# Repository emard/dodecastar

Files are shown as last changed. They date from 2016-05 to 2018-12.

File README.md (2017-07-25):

# Dodecastar

Star-shaped 3D printable object "useful" as a lamp shade
for a string of WS2812B LEDs for Xmas decoration lights.

Dodecastar is a dodecahedron based shape with
12 five-pointed stars, inspired by vintage Xmas
lights from 1960's, made of clear transparent plastic. 
Shape is modified into 2 halves for mounting on LED string.

Written in openscad. To visualize light reflection in
transparent material, it could be exported to "OFF" 
format and imported into Blender.
Example [pictures](/pic/)

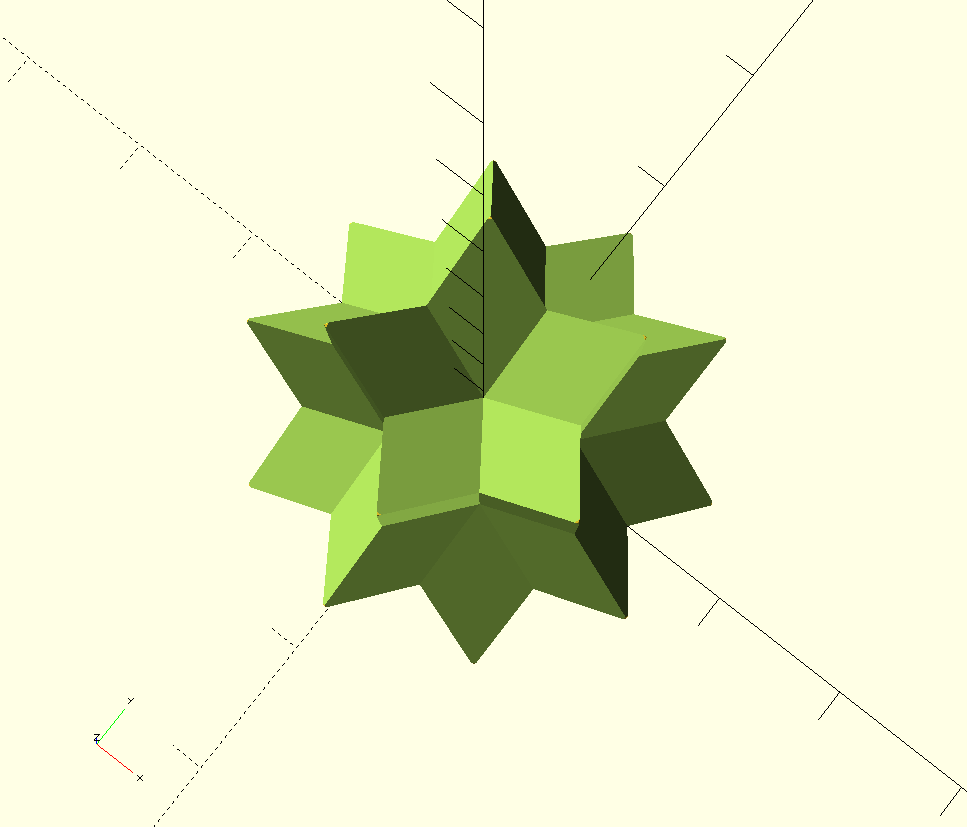
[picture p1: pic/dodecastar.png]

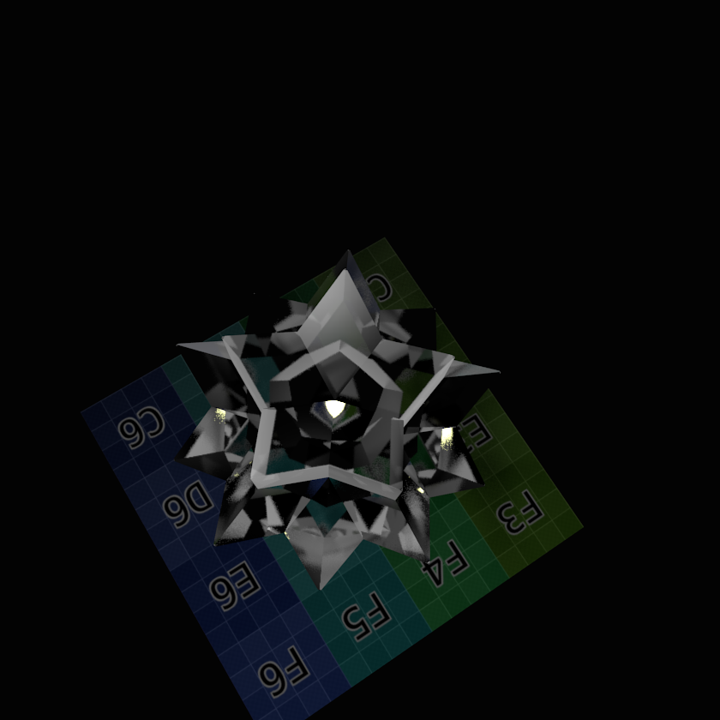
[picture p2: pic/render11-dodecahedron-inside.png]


# Xmas Lights Assembly

The dodecastars are intended to be mounted on a string of
[50Pcs.WS2812B Pre-wired LEDs](http://www.ebay.com/itm/50Pcs-WS2812B-Pre-wired-LED-Pixel-Module-String-Light-Full-Color-5050-RGB-5V-TZ-/201965803082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).

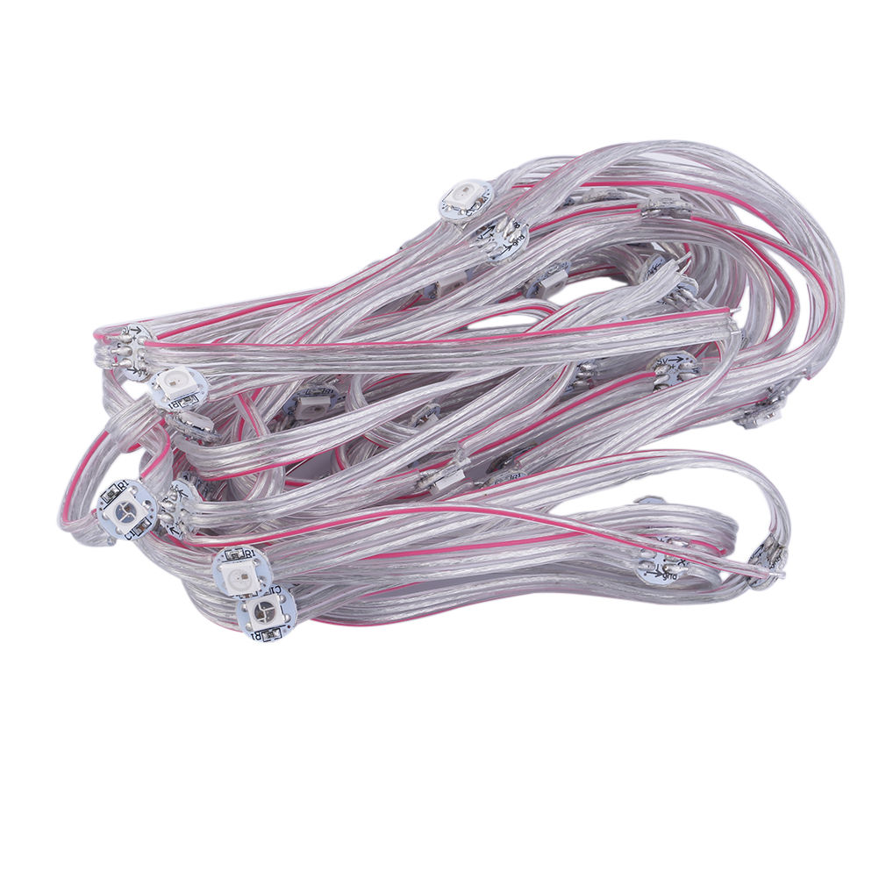
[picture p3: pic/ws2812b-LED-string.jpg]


Each star consists of 2 identical halves, so let's print 100 of them
with transparent colorless filament (I recommend PET-G), infill 0%.
Printing each half takes about 7 minutes. It will appear
as icy-white. It would be ideal if it were really
transparent, but filament extrusion can't make it.

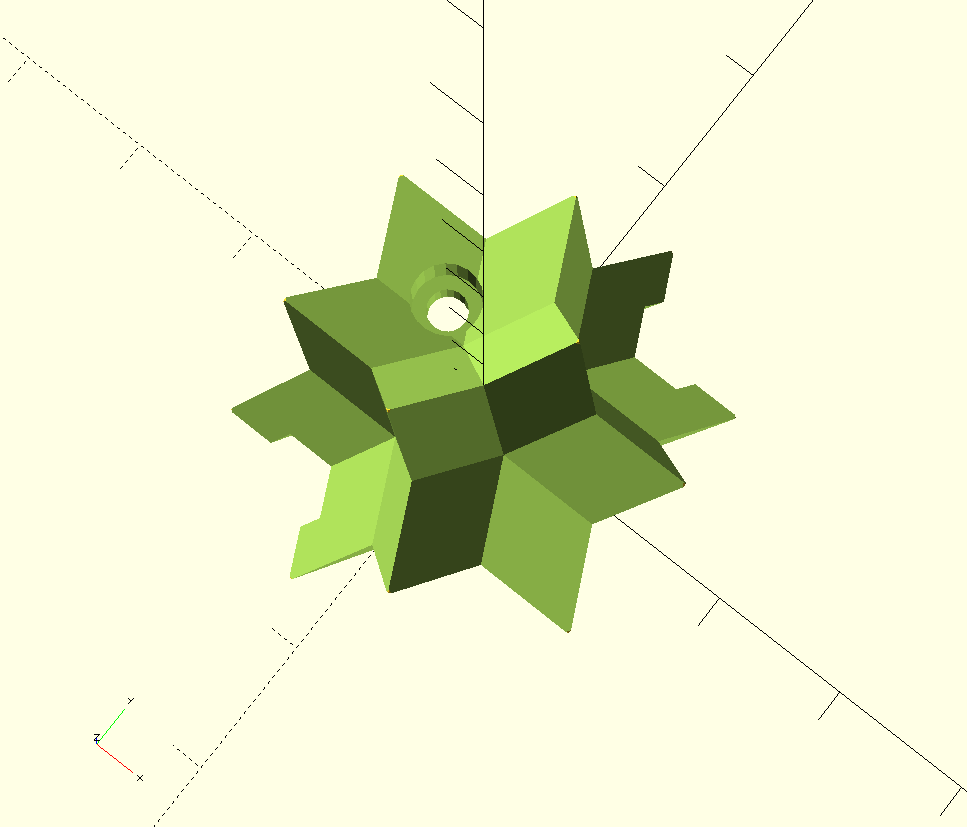
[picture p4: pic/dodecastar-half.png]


Tighten 2 halves of dodecastar gently with 2 small inox screws for 
plastic with round philips head, thread dia: 2.2 mm, thread length: 6 mm.

Carefully handle new LED strip. Soldered connections cannot 
stand any mechanical force. Only mounted dodecastars provide
mechanical strength to whole LED strip.

Solder the USB A male connector on Din side of WS2812B module.
I strongly recommend pinout compatible with normal USB,
so that it can be accidentaly plugged into PC without
any damage, but it will not light up yet because WS2812B 
needs different signal protocol.

    WS2812B    USB-A
    -------    -----
    GND        GND
    Din        D+
               D-
    +5V        +5V

# Hardware

Various [Arduino](http://arduino.cc) compatible hardware 
should work, even ATTINY85.
I use ESP8266 NodeMCU 0.9 with GPIO14 connected to LED Din
(GPIO14 is arduino Pin 2, on NodeMCU is labeled "D5").
Connect GND and 5V from the board to LED strip.
No resistors or capacitors needed for NodeMCU.

# Software

Install [Arduino](http://arduino.cc) and
core support if required for your board.
NodeMCU boards require 
[ESP8266 core for Arduino ](https://github.com/esp8266/Arduino).

Download
[Adafruit NeoPixel library](https://github.com/adafruit/Adafruit_NeoPixel),
copy it to ~/Arduino/libraries/Adafruit_NeoPixel
and restart arduino.

Open Examples->Adafruit NeoPixel->Strandtest.
Edit source to set right PIN connected to "Din"
(pin 14 in my case) and number of LEDs on the strip
(I have 50).

    #define PIN 14 // Arduino pin 14 = NodeMCU pin D5
    Adafruit_NeoPixel strip = Adafruit_NeoPixel(50, PIN, NEO_GRB + NEO_KHZ800);

Compile and upload, whole LED string will light up and
constantly change beautiful colors!

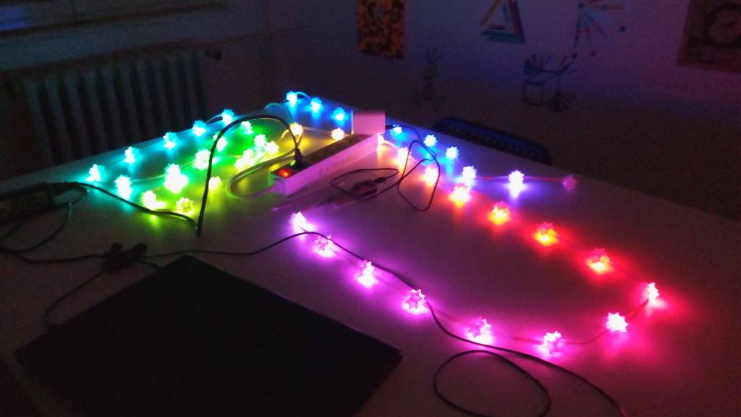
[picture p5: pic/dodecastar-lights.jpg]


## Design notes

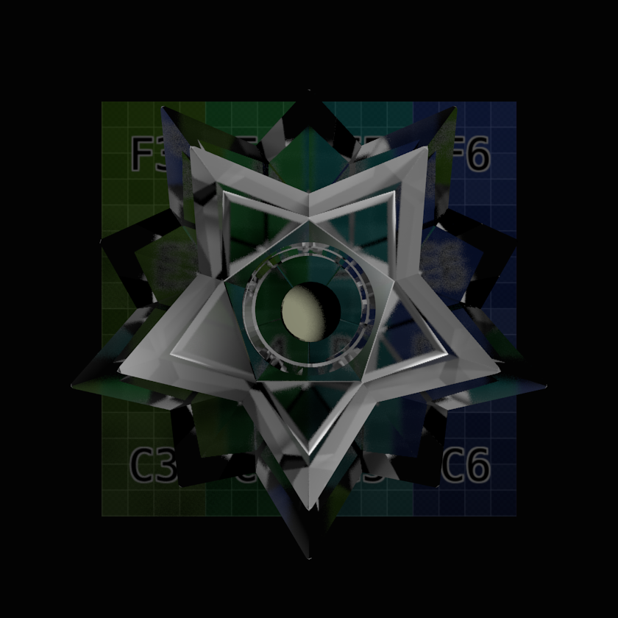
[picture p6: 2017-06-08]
pic/render01-star-inside.png

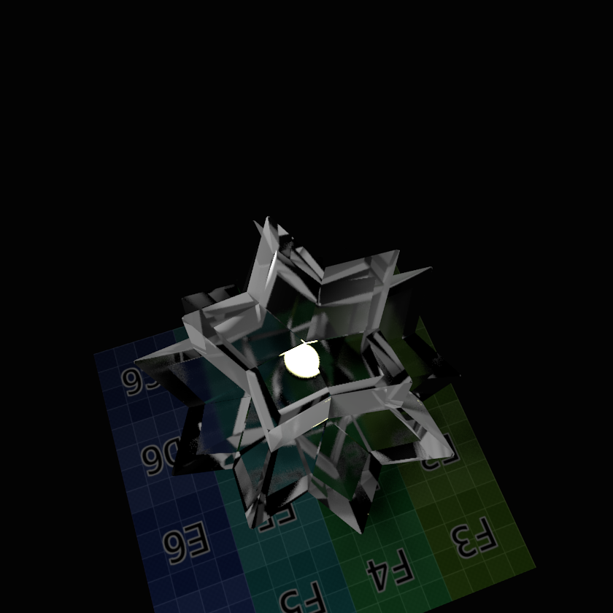
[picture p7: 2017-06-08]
pic/render02-star-inside.png

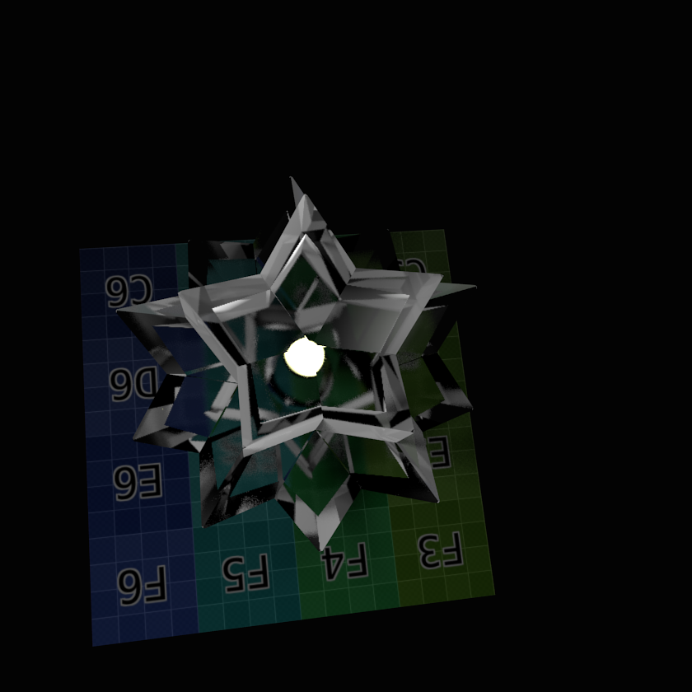
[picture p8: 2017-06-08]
pic/render03-star-inside.png

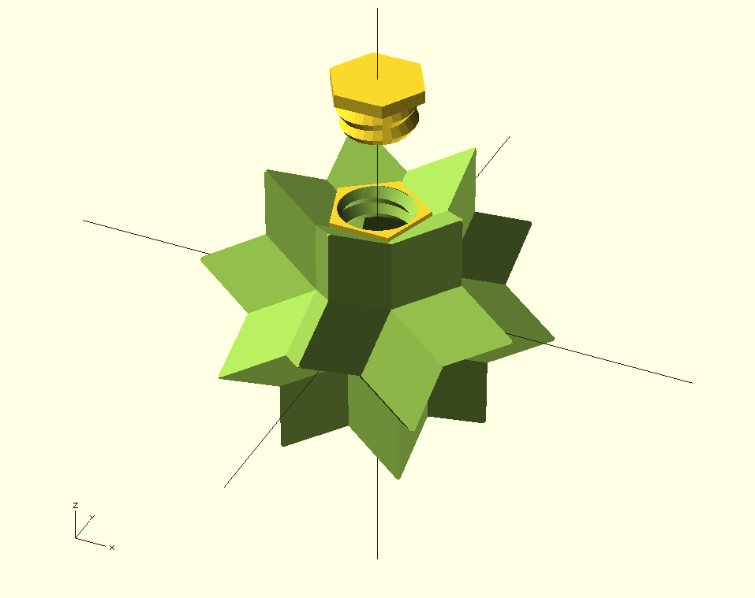
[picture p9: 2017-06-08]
pic/dodecastar12.png

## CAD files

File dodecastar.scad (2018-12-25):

include <polyScrewThread.scad>

/*
todo:
[ ] no thread
[ ] cable strength release
[ ] lamp socket
*/

//create a dodecahedron by intersecting 6 boxes

module pentagonal_cut_up(d, u = 0)
{
  translate([0,0,0.500001-d/2])
    rotate([0,0,90+72/2])
      cylinder(h = d, r1 = 0, r2 = sqrt(2) / 3 - u, $fa = 360/5, $fs = 0.1, center=true);
}

module pentagonal_cut_down(d, u = 0)
{
  translate([0,0,-0.500001+d/2])
    rotate([0,0,90])
      cylinder(h = d, r2 = 0, r1 = sqrt(2) / 3 - u, $fa = 360/5, $fs = 0.1, center = true);
}

/* two pentagonal pyramids, facing peak-to-peak */
/* d - cut depth 
** u - leave uncut edge
*/
module pentagonal_cutter(d, u = 0)
{
  pentagonal_cut_up(d, u);
  pentagonal_cut_down(d, u);
}

/* 
   h = height (mm) (original prism reflector is 43 mm high)

   d = cut depth (unit 0-no cut 1-cut all)
   u = uncut edge roudoff (0-sharp 0.005-slightly rounded)
   l = 0-cut all edges 1-leave top edge uncut

   spiky star with spikes roundoff: d=0.233, u = 0.005
   spiky star with sharp spikes: d=0.233, u = 0

   original:  dodecastar(43, 0.2, u = 0.005);
   improved:  dodecastar(43, 0.233, u = 0.005);
*/
module dodecastar(height = 1, d = 0.233, u = 0.005, l = 0)
{
  scale([height,height,height]) //scale by height parameter
  {
    difference()
    {
      intersection(){
        // make a cube
        cube([2,2,1], center = true); 
        intersection_for(i=[0:4]) //loop i from 0 to 4, and intersect results
        { 
          //make a cube, rotate it 116.565 degrees (dihedral angle)  around the X axis,
          // dihedral angle:
          // golden_ratio = (1 + sqrt(5)) / 2
          // dihedral_angle = 2 * atan(golden_ratio)
          // dihedral_angle = 2 * atan((1 + sqrt(5)) / 2)
          //then 72*i around the Z axis
          rotate([0,0,72*i])
            rotate([2 * atan((1 + sqrt(5)) / 2),0,0])
              cube([2,2,1], center = true); 
        }
      }

      union()
      {
        rotate([0,0,72/2])
          if(l < 0.5)
            pentagonal_cutter(d, u);
          else
            pentagonal_cut_down(d, u);
        for(i = [0:4])
        {
          rotate([0,0,72*i])
            rotate([2 * atan((1 + sqrt(5)) / 2),0,0])
              pentagonal_cutter(d, u);
        }
      }
    }
  }
}

//create a dodecahedron by intersecting 6 boxes
module dodecahedron(height) 
{
        scale([height,height,height]) //scale by height parameter
        {
                intersection(){
                        //make a cube
                        cube([2,2,1], center = true); 
                        intersection_for(i=[0:4]) //loop i from 0 to 4, and intersect results
                        { 
                                //make a cube, rotate it dihedral angle 116.565 degrees around the X axis,
                                // dihedral angle:
                                // golden_ratio = (1 + sqrt(5)) / 2
                                // dihedral_angle = 2 * atan(golden_ratio)
                                // dihedral_angle = 2 * atan((1 + sqrt(5)) / 2)
                                //then 72*i around the Z axis
                                rotate([0,0,72*i])
                                        rotate([2 * atan((1 + sqrt(5)) / 2),0,0])
                                        cube([2,2,1], center = true); 
                        }
                }
        }
}

/* make a lamp hole in the reflector 
** height in mm
** ih: interior dodecastar lamp hole factor (0.7) relative to height
** id: interior dodecastar cut depth (0.15)
** extup: screw hole reinforcement height factor (0.25) relative to height
** interface 0-none, 1-screw hole, 2-ledstrip pass-thru, 3-ledstrip half with 2 screws
interior dodecastar : ih = 0.7, id = 0.15, extup = 0.25
interior simple dodecahedron : ih = 0.5, id = 0, extup = 0.25
*/
module reflector(height = 43, ih = 0.5, id = 0.0, extup = 0.22,
// for interface=3
screw_pos=7,
screw=2.2, screw_thread_d=2.2*0.8, screw_hole_d=2.2*1.3, screw_head_d=2.2*2.2,
screw_head_h=2.2*0.6, screw_length=9.5,
nut_height=1.0, nut_d=2.2*2.1,
cable_w=6, cable_h=1.8,
interface=3)
{
  // additional stuff for interface=3
  star_angle=atan((1 + sqrt(5)) / 2);
  screw_height=screw_length/2-screw_head_h; // height without the head
  rotate([0,interface==3 ? 270 : 0,0])
  union()
  {
    difference()
    {
      union() // material volume
      {
        dodecastar(height);
        /* lamp screw hole, reinforced with extruded pentagon
        ** 0.233 is the cut depth of outer dodecastar
        ** 0.1 is the internal dodecastar-hole cut depth */
        if(interface == 1)
          translate([0,0,height*ih/2 * (1-2*id)])
            rotate([0,0,90])
              cylinder(h = height*(extup+1-0.233*2-ih*(1-2*id))/2, r = 8, $fa = 360/5, $fs = 0.1);
      }
      union() // void volume
      {
        /* cut out dodecastar interior for the lamp */
        // dodecahedron(height*ih);
        dodecastar(height*ih, d = id, u = 0, l = 0);
        /* cut out the screw thread, translate and length same as reinforcement */
/*           8,  // Height 
 *           3,  // Step height (the half will be used to countersink the ends)
 *          55,  // Degrees (same as used for the screw_thread example)
 *          15,  // Outer diameter of the thread to match
 *         0.5)  // Resolution, you may want to set this to small values cca 0.5
 *                  (quite high res) to minimize overhang issues 
 */
        if(interface==1)
          translate([0,0,height*ih/2 * (1-2*id)])
            thread_cut(height*(extup+1-0.233*2-ih*(1-2*id))/2,3,55,12.4,0.5);
        if(interface==2)
          rotate([0,0,30])
          {
            translate([0,-2,0])
              cube([9,3,height], center=true);
            cube([13,1,height], center=true);
          }
        if(interface==3)
        {
          // cube to cut off half-star
          translate([-height,0,0])
            cube([2*height,2*height,2*height], center=true);
          // box to cut off cable holder slit
          rotate([star_angle,0,0])
            cube([cable_h,cable_w,height*1.1],center=true);
          // cylinder to drill screw thru-hole
          // just drill screw head hole thru above
          rotate([0,90,0])
            rotate([0,0,star_angle])
              translate([0,screw_pos,screw_height])
                cylinder(d=screw_head_d-0.001,h=height+0.002,$fn=20,center=false);
          // screw leader hole thru all
          rotate([0,90,0])
            rotate([0,0,star_angle])
              translate([0,screw_pos,-0.001])
                cylinder(d=screw_hole_d,h=height+0.002,$fn=20,center=false);
          // screw hole for the thread
          rotate([0,90,0])
            rotate([0,0,star_angle])
              translate([0,-screw_pos,-0.001])
                cylinder(d=screw_thread_d,h=height*0.22+0.002,$fn=20,center=false);
          // screw leader hole for thread clearance
          rotate([0,90,0])
            rotate([0,0,star_angle])
              translate([0,-screw_pos,-0.001])
                cylinder(d=screw_hole_d,h=nut_height+0.002,$fn=20,center=false);
        }
      }
    }
    if(interface == 3) // post-added volume
    {
      // plastic nut for screw thread
      rotate([0,90,0])
        rotate([0,0,star_angle])
        union()
        {
           translate([0,-screw_pos,height/10+nut_height/2])
             difference()
             {
               cylinder(d=nut_d,h=height/5-nut_height,$fn=20,center=true);
               // hole in the nut for screw thread
               cylinder(d=screw_thread_d,h=height,$fn=20,center=true);
             }
           translate([0,screw_pos,0])
             difference()
             {
               union()
               {
               // the material (the nut)
               // 1.5 mm add to diameter for screw holder thickness
               translate([0,0,nut_height])
                 cylinder(d1=nut_d,d2=screw_head_d+1.5,h=screw_height-nut_height,$fn=20,center=false);
               translate([0,0,screw_height])
                 cylinder(d=screw_head_d+1.5,h=height*0.22-screw_height,$fn=20,center=false);
               }
               // hole in the screw leader
               union()
               {
                 // thru-hole, more than long enough
                 cylinder(d=screw_hole_d, h=height, $fn=20, center=true);
                 // conical screw head
                 translate([0,0,screw_height])
                   cylinder(d1=screw_hole_d,d2=screw_head_d,h=screw_head_h, $fn=20, center=false);
                 translate([0,0,screw_height+screw_head_h])
                   cylinder(d=screw_head_d,h=height,$fn=20,center=false);
               }
             }
        }
    }
  }
}

/* for 3d printing */
/* minimal size (cca 0.5x normal size) that fits ledstrip */
if(1)
    reflector(height=27, screw_head_h=0.001, screw_length=5, cable_h=2.2, interface=3);
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

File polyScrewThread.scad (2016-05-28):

/*
 *    polyScrewThread.scad    by aubenc @ Thingiverse
 *
 * This script contains the library modules that can be used to generate
 * threaded rods, screws and nuts.
 *
 * http://www.thingiverse.com/thing:8796
 *
 * CC Public Domain
 */

module screw_thread(od,st,lf0,lt,rs,cs)
{
    or=od/2;
    ir=or-st/2*cos(lf0)/sin(lf0);
    pf=2*PI*or;
    sn=floor(pf/rs);
    lfxy=360/sn;
    ttn=round(lt/st)+1;
    zt=st/sn;

    intersection()
    {
        if (cs >= -1)
        {
           # thread_shape(cs,lt,or,ir,sn,st);
        }

        full_thread(ttn,st,sn,zt,lfxy,or,ir);
    }
}

module hex_nut(df,hg,sth,clf,cod,crs)
{

    difference()
    {
        hex_head(hg,df);

        hex_countersink_ends(sth/2,cod,clf,crs,hg);

        screw_thread(cod,sth,clf,hg,crs,-2);
    }
}

module thread_cut(hg,sth,clf,cod,crs)
{
    union()
    {
        hex_countersink_ends(sth/2,cod,clf,crs,hg);
        screw_thread(cod,sth,clf,hg,crs,-2);
    }
}

module hex_screw(od,st,lf0,lt,rs,cs,df,hg,ntl,ntd)
{
    ntr=od/2-(st/2+0.1)*cos(lf0)/sin(lf0);

    union()
    {
        hex_head(hg,df);

        translate([0,0,hg])
        if ( ntl == 0 )
        {
            cylinder(h=0.01, r=ntr, center=true);
        }
        else
        {
            if ( ntd == -1 )
            {
                cylinder(h=ntl+0.01, r=ntr, $fn=floor(od*PI/rs), center=false);
            }
            else if ( ntd == 0 )
            {
                union()
                {
                    cylinder(h=ntl-st/2,
                             r=od/2, $fn=floor(od*PI/rs), center=false);

                    translate([0,0,ntl-st/2])
                    cylinder(h=st/2,
                             r1=od/2, r2=ntr, 
                             $fn=floor(od*PI/rs), center=false);
                }
            }
            else
            {
                cylinder(h=ntl, r=ntd/2, $fn=ntd*PI/rs, center=false);
            }
        }

        translate([0,0,ntl+hg]) screw_thread(od,st,lf0,lt,rs,cs);
    }
}

module thread_shape(cs,lt,or,ir,sn,st)
{
    if ( cs == 0 )
    {
        cylinder(h=lt, r=or, $fn=sn, center=false);
    }
    else
    {
        union()
        {
            translate([0,0,st/2])
              cylinder(h=lt-st+0.005, r=or, $fn=sn, center=false);

            if ( cs == -1 || cs == 2 )
            {
                cylinder(h=st/2, r1=ir, r2=or, $fn=sn, center=false);
            }
            else
            {
                cylinder(h=st/2, r=or, $fn=sn, center=false);
            }

            translate([0,0,lt-st/2])
            if ( cs == 1 || cs == 2 )
            {
                  cylinder(h=st/2, r1=or, r2=ir, $fn=sn, center=false);
            }
            else
            {
                cylinder(h=st/2, r=or, $fn=sn, center=false);
            }
        }
    }
}

module full_thread(ttn,st,sn,zt,lfxy,or,ir)
{
    for(i=[0:ttn-1])
    {
        for(j=[0:sn-1])
        {
            polyhedron(
                  points=[
                          [0,                  0,                  i*st-st            ],
                          [ir*cos((j+1)*lfxy), ir*sin((j+1)*lfxy), i*st+(j+1)*zt-st   ],
                          [ir*cos(j*lfxy),     ir*sin(j*lfxy),     i*st+j*zt-st       ],
                          [or*cos((j+1)*lfxy), or*sin((j+1)*lfxy), i*st+(j+1)*zt-st/2 ],
                          [or*cos(j*lfxy),     or*sin(j*lfxy),     i*st+j*zt-st/2     ],
                          [0,                  0,                  i*st+st            ],
                          [ir*cos((j+1)*lfxy), ir*sin((j+1)*lfxy), i*st+(j+1)*zt      ],
                          [ir*cos(j*lfxy),     ir*sin(j*lfxy),     i*st+j*zt          ]
                         ],
               faces=[
                          [0,1,2],
                          [5,6,3],[5,3,0],[0,3,1],
                          [3,4,1],[1,4,2],
                          [3,6,4],[4,6,7],
                          [0,2,4],[0,4,5],[5,4,7],
                          [5,7,6]
                         ],
               convexity=5);
        }
    }
}

module hex_head(hg,df)
{
    cylinder(h=hg, r=df/2/sin(60), $fn=6, center=false);
}

module hex_countersink_ends(chg,cod,clf,crs,hg)
{
    translate([0,0,-0.1])
    cylinder(h=chg+0.01, 
             r1=cod/2, 
             r2=cod/2-(chg+0.1)*cos(clf)/sin(clf),
             $fn=floor(cod*PI/crs), center=false);

    translate([0,0,hg-chg+0.1])
    cylinder(h=chg+0.01, 
             r1=cod/2-(chg+0.1)*cos(clf)/sin(clf),
             r2=cod/2, 
             $fn=floor(cod*PI/crs), center=false);
}

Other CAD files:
upbox.scad
dodecastar.blend

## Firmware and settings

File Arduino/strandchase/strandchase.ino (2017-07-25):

#include <Adafruit_NeoPixel.h>
#ifdef __AVR__
  #include <avr/power.h>
#endif

#define PIN 14 // Arduino pin 14 = NodeMCU pin D5
#define NUM_LEDS 50
// web interface is stable up to 5 LEDs
// for more, web interface will stop working after few clicks
// workaround: in Adafruit_NeoPixel.cpp around line 149
// comment out "noInterrupts()" call
// /*  noInterrupts(); */
// LEDs will flicker with interrupts ON, but web interface should be stable
// Interrupts can be turned ON/OFF with "FLICKER" web button

// Parameter 1 = number of pixels in strip
// Parameter 2 = Arduino pin number (most are valid)
// Parameter 3 = pixel type flags, add together as needed:
//   NEO_KHZ800  800 KHz bitstream (most NeoPixel products w/WS2812 LEDs)
//   NEO_KHZ400  400 KHz (classic 'v1' (not v2) FLORA pixels, WS2811 drivers)
//   NEO_GRB     Pixels are wired for GRB bitstream (most NeoPixel products)
//   NEO_RGB     Pixels are wired for RGB bitstream (v1 FLORA pixels, not v2)
//   NEO_RGBW    Pixels are wired for RGBW bitstream (NeoPixel RGBW products)
Adafruit_NeoPixel strip = Adafruit_NeoPixel(NUM_LEDS, PIN, NEO_GRB + NEO_KHZ800);

// IMPORTANT: To reduce NeoPixel burnout risk, add 1000 uF capacitor across
// pixel power leads, add 300 - 500 Ohm resistor on first pixel's data input
// and minimize distance between Arduino and first pixel.  Avoid connecting
// on a live circuit...if you must, connect GND first.

// remote updates over the air
// (>1M flash required)
#define USE_OTA 0

#define SERIAL_VERBOSE 0


// includes
#include <ESP8266WiFi.h>
#include <ESP8266mDNS.h>
#include <WiFiUdp.h>
#include <FS.h>
#if USE_OTA
#include <ArduinoOTA.h>
#endif
#include <ESP8266WebServer.h>

/**
 * mDNS and OTA Constants
 */
#define HOSTNAME "dodecastar-" ///< Hostename. The setup function adds the Chip ID at the end.
/// @}

#define COUNTDOWN_CYCLES 10
int countdown = COUNTDOWN_CYCLES; // improve web stability after clicking, do some loop() cycles without ledstrip update
int allow_interrupts = 1; // no interrupts: web stability only with no interrupts, interrupts: noflicker
int program_control = 1; // blink leds using program control
int program_speed = 5; // how fast
int program_density = 2; // how dense does the color changes between pixels
int program_brightness = 50; // intensity of the LEDs
uint32_t selected_color = strip.Color(100,100,100); // medium white
uint8_t use_color = 0;

/**
 * Default WiFi connection information.
 */
const char* ap_default_ssid = "ra"; ///< Default SSID.
const char* ap_default_psk = "GigabyteBrix"; ///< Default PSK.
//const char* ap_default_psk = ""; ///< Default PSK.
const char* config_name = "./dodecastar.conf";
// set to 0 to start with default ssid/psk
#define LOAD_CONFIG 1
int ap_mode=0;

String current_ssid = ap_default_ssid;
String current_psk = ap_default_psk;

String message = "";
ESP8266WebServer server(80);
String webString="";     // String to display (runtime modified)

// too many controls will make web interface unstable
// enable checkbox for leds
#define WEB_TAB_CHECKBOX 0
// enable on-off buttons for leds
#define WEB_TAB_BUTTON 1
// enable individual color selectors
#define WEB_TAB_COLOR 0


int ssr_cols = 5, ssr_rows = NUM_LEDS/5; // ssr display shown as table cols x rows

uint32_t led_color[NUM_LEDS];
uint8_t led_on[NUM_LEDS]; // click for on/off

int nextline(String content, int pos1)
{
  // Check if there is a second line available.
  int16_t pos = content.substring(pos1).indexOf("\r\n");
  uint16_t le = 2;
  // check for linux and mac line ending.
  if (pos == -1)
  {
    le = 1;
    pos = content.substring(pos1).indexOf("\n");
    if (pos == -1)
      pos = content.substring(pos1).indexOf("\r");
  }
  if(pos == -1)
    return -1;
  return pos1+pos+le; // to start of next line  
}

/**
 * Read WiFi connection information from file system.
 * ssid String pointer for storing SSID.
 * pass String pointer for storing PSK.
 * return True or False.
 * 
 * The config file have to containt the WiFi SSID in the first line
 * and the WiFi PSK in the second line.
 * Line seperator can be \r\n (CR LF) \r or \n.
 */
bool loadConfig(String *ssid, String *pass)
{
  // open file for reading.
  File configFile = SPIFFS.open(config_name, "r");
  if (!configFile)
  {
    Serial.print("Failed to load ");
    Serial.println(config_name);
    return false;
  }

  // Read content from config file.
  String content = configFile.readString();
  configFile.close();
  
  content.trim();

  // Check if there is a second line available.
  int16_t pos = content.indexOf("\r\n");
  uint16_t le = 2;
  // check for linux and mac line ending.
  if (pos == -1)
  {
    le = 1;
    pos = content.indexOf("\n");
    if (pos == -1)
      pos = content.indexOf("\r");
  }

  // If there is no second line: Some information is missing.
  if (pos == -1)
  {
    Serial.println("Infvalid content.");
    Serial.println(content);
    return false;
  }

  // check for the third line
  // Check if there is a second line available.
  int16_t pos2 = content.indexOf("\r\n", pos + le + 1);
  uint16_t le2 = 2;
  // check for linux and mac line ending.
  if (pos2 == -1)
  {
    le2 = 1;
    pos2 = content.indexOf("\n", pos + le + 1);
    if (pos2 == -1)
      pos2 = content.indexOf("\r", pos + le + 1);
  }
  
  // If there is no third line: Some information is missing.
  if (pos2 == -1)
  {
    Serial.println("Invalid content.");
    Serial.println(content);
    return false;
  }

  // Store SSID and PSK into string vars.
  *ssid = content.substring(0, pos);
  *pass = content.substring(pos + le, pos2);

  // get LED state
  pos = pos2 + le2;
  for(int i = 0; i < NUM_LEDS && pos2 >= 0; i++)
  {
    pos2 = nextline(content, pos);
    if(pos >= 0)
    {
      led_color[i] = content.substring(pos,pos2).toInt();
      led_on[i] = led_color[i] ? 1 : 0;
    }
    pos = pos2;
  }
  output_state();

  ssid->trim();
  pass->trim();

#ifdef SERIAL_VERBOSE
  Serial.println("----- connection -----");
  Serial.println("ssid: " + *ssid);
  Serial.println("psk:  " + *pass);
#endif

  return true;
} // loadConfig


/**
 * @brief Save WiFi SSID and PSK to configuration file.
 * @param ssid SSID as string pointer.
 * @param pass PSK as string pointer,
 * @return True or False.
 */
bool saveConfig(String *ssid, String *pass)
{
  // Open config file for writing.
  File configFile = SPIFFS.open(config_name, "w");
  if (!configFile)
  {
    Serial.print("Failed to save ");
    Serial.println(config_name);
    return false;
  }

  // Save SSID and PSK.
  configFile.println(*ssid);
  configFile.println(*pass);

  for(int i = 0; i < NUM_LEDS; i++)
  {
    configFile.println(led_on[i] ? led_color[i] : 0);
    // Serial.println(led_color[i]);
  }
  configFile.close();
  Serial.print("config saved: ");
  Serial.println(config_name);
  return true;
} // saveConfig

// format filesystem (erase everything)
// place default password file
void format_filesystem(void)
{
  String station_ssid = ap_default_ssid;
  String station_psk = ap_default_psk;

  Serial.println("Formatting"); // erase everything
  SPIFFS.format();
  
  Serial.println("Saving factory default");
  saveConfig(&station_ssid, &station_psk);
}

// output led state to hardware pins
void output_state()
{
  for(int i = 0; i < strip.numPixels() && i < NUM_LEDS; i++)
    strip.setPixelColor(i, led_on[i] ? led_color[i] : 0);
}


// greate html table
// that displays ssr state
// in color and has submit buttons
void create_message()
{
  int n = 0;
  message =
"<style type=\"text/css\">"
"input[type=checkbox]"
"{"
 "/* Double-sized Checkboxes */"
 "-ms-transform: scale(2); /* IE */"
 "-moz-transform: scale(2); /* FF */"
 "-webkit-transform: scale(2); /* Safari and Chrome */"
 "-o-transform: scale(2); /* Opera */"
 "padding: 10px;"
"}"
"</style>"
"<head>"
"<meta http-equiv=\"cache-control\" content=\"max-age=0\" />"
"<meta http-equiv=\"cache-control\" content=\"no-cache\" />"
"<meta http-equiv=\"expires\" content=\"0\" />"
"<meta http-equiv=\"expires\" content=\"Tue, 01 Jan 1980 1:00:00 GMT\" />"
"<meta http-equiv=\"pragma\" content=\"no-cache\" />"
"</head>"
            "<a href=\"/\">refresh</a> "
            "<a href=\"setup\">setup</a> "
            "<a href=\"cssButton\">cssButton</a> "
            "<p/>"
            "<form action=\"/update\" method=\"get\" autocomplete=\"off\">";
  char hexcolor[10];
  sprintf(hexcolor, "#%06X", selected_color);
  // color for LED on/off
  message +=     "COLOR "
                 "<input type=\"color\" name=\"selected_color" + String(n) + "\" value=\"" + String(hexcolor) + "\"> </input>"
                 "<input type=\"checkbox\" name=\"use_color\" " + String(use_color ? " checked" : "") + "> </input>"
                 "<p/>";
  // this controls each individual LED on the strip
  message += "<table>";
  for(int y = 0; y < ssr_rows; y++)
  {
    message += "<tr>";
    for(int x = 0; x < ssr_cols; x++)
    {
      sprintf(hexcolor, "#%06X", led_color[n]);
      message += "<td bgcolor=\"" + String(hexcolor) + "\">"
               #if WEB_TAB_CHECKBOX
               + "<input type=\"checkbox\" name=\"check" + String(n) + "\" " + String(led_on[n] ? " checked" : "") + "> </input>"
               #endif
               #if WEB_TAB_COLOR
               + "<input type=\"color\" name=\"color" + String(n) + "\" value=\"" + String(hexcolor) + "\"> </input>"
               #endif
               #if WEB_TAB_BUTTON
               + "<button type=\"submit\" name=\"button"
               + String(n) 
               + "\" value=\"" 
               + String(led_on[n] ? "0" : "1") 
               + "\">" // toggle when clicked 
               + String(led_on[n] ? "ON" : "OFF") // current state
               + "</button>"
               #endif
                 "</td>";
      n++; // increment ssr number
    }
    message += "</tr>";
  }
  message += "</table>";
  // interrupts on/off
  message +=     "FLICKER "
                 " <button type=\"submit\" name=\"interrupt_btn\" value=\"" 
               + String(allow_interrupts ? "0" : "1") 
               + "\">" // toggle when clicked 
               + String(allow_interrupts ? "ON" : "OFF") // current state
               + "</button>"
               + String(allow_interrupts ? "" : " if LED strip stops responding, power OFF/ON")
               + "<p/>";
  // program control on/off
  message +=     "PROGRAM "
                 " <button type=\"submit\" name=\"program_btn\" value=\"" 
               + String(program_control ? "0" : "1") 
               + "\">" // toggle when clicked 
               + String(program_control ? "ON" : "OFF") // current state
               + "</button>"
                 "<p/>";
  // program speed
  message +=     "SPEED "
               " <input type=\"number\" name=\"speed\" value=\"" 
               + String(program_speed) 
               + "\" min=\"1\" max=\"10\">"
                 "<p/>";
  // program density
  message +=     "DENSITY "
               " <input type=\"number\" name=\"density\" value=\"" 
               + String(program_density)
               + "\" min=\"1\" max=\"10\">"
                 "<p/>";
  // program brightness
  message +=     "BRIGHTNESS "
               " <input type=\"number\" name=\"brightness\" value=\"" 
               + String(program_brightness)
               + "\" min=\"0\" max=\"256\">"
                 "<p/>";

  message += "<button type=\"submit\" name=\"apply\" value=\"1\">Apply</button>"
             "<button type=\"submit\" name=\"save\" value=\"1\">Save</button>";
 
  message += "</form>";
}

// when user requests root web page
void handle_root()
{
  create_message();
  server.send(200, "text/html", message);
  countdown = COUNTDOWN_CYCLES;
}

void handle_setup() {
  String new_ssid = "", new_psk = "";
  webString = "<form action=\"/setup\" method=\"get\" autocomplete=\"off\">"
              "Access point: <input type=\"text\" name=\"ssid\"><br>"
              "Password: <input type=\"text\" name=\"psk\"><br>"
              "<button type=\"submit\" name=\"apply\" value=\"1\">Apply</button>"
              "<button type=\"submit\" name=\"discard\" value=\"1\">Discard</button>"
              "</form>";
  for(int i = 0; i < server.args(); i++)
  {
    if(server.argName(i) == "discard")
    {
      loadConfig(&current_ssid, &current_psk);
      create_message();
      webString = message;
    }
    if(server.argName(i) == "apply")
    {
      for(int j = 0; j < server.args(); j++)
      {
        if(server.argName(j) == "ssid")
        {
          new_ssid = server.arg(j);
        }
        if(server.argName(j) == "psk")
        {
          new_psk = server.arg(j);
        }
      }
      if(new_ssid.length() > 0 && new_psk.length() >= 8)
      {
        //Serial.println("Save config");
        current_ssid = new_ssid;
        current_psk = new_psk;
        //saveConfig(&current_ssid, &current_psk);
        //reboot = 1;
        //loadConfig(&current_ssid, &current_psk);
        create_message();
        webString = message 
          + String("Click Save for new login:<p/>")
          + "Access point: " + current_ssid + "<br/>"
          + "Password: " + current_psk + "<p/>"
          + "Settings will be active after next power up.";
      }
    }
  }
  server.send(200, "text/html", webString);            // send to someones browser when asked
  countdown = COUNTDOWN_CYCLES;
}

void handle_update() {
  // first obtain selected color
  char hexcolor[10];
  uint32_t bincolor;
  int color_need = 2; // helps earlier exit
  for(int i = 0; i < server.args() && color_need > 0; i++)
  {
    if(server.argName(i).startsWith("selected_color"))
    {
      server.arg(i).substring(1).toCharArray(hexcolor, 7);
      bincolor = strtol(hexcolor, NULL, 16);
      selected_color = strip.Color((bincolor >> 16) & 255, (bincolor >> 8) & 255, bincolor & 255);
      color_need--;
    }
    if(server.argName(i).startsWith("use_color"))
    {
      use_color = (server.arg(i) == "on") ? 1 : 0;
      color_need--;
    }
  }
  // Apply or Save button
  for(int i = 0; i < server.args(); i++)
  {
    if(server.argName(i) == "apply" || server.argName(i) == "save")
    {
      #if WEB_TAB_CHECKBOX
      // assume all LEDs are off
      for(int j = 0; j < NUM_LEDS; j++)
        led_on[j] = 0;
      #endif
      for(int j = 0; j < server.args(); j++)
      {
        #if WEB_TAB_CHECKBOX
        if(server.argName(j).startsWith("check"))
        {
          int n = server.argName(j).substring(5).toInt();
          if(n >= 0 && n < NUM_LEDS)
            if(server.arg(j) == "on")
              led_on[n] = 1;
        }
        #endif
        #if WEB_TAB_COLOR
        if(server.argName(j).startsWith("color"))
        {
          int n = server.argName(j).substring(5).toInt();
          if(n >= 0 && n < NUM_LEDS)
          {
            server.arg(j).substring(1).toCharArray(hexcolor, 7);
            bincolor = strtol(hexcolor, NULL, 16);
            led_color[n] = strip.Color((bincolor >> 16) & 255, (bincolor >> 8) & 255, bincolor & 255);
          }
        }
        #endif
      }
    }
    if(server.argName(i) == "save")
      saveConfig(&current_ssid, &current_psk);
  }
  // ON/OFF buttons
  for(int i = 0; i < server.args(); i++)
  {
    #if WEB_TAB_BUTTON
    if(server.argName(i).startsWith("button"))
    {
      int n = server.argName(i).substring(6).toInt();
      if(n >= 0 && n < NUM_LEDS)
      {
        uint8_t led_on_off = server.arg(i).toInt() ? 1 : 0;
        if(led_on[n] != led_on_off) // state changed
        {
          led_on[n] = led_on_off;
          if(use_color)
            led_color[n] = selected_color;
        }
      }
    }
    #endif
    if(server.argName(i).startsWith("interrupt_btn"))
      allow_interrupts = server.arg(i).toInt();
    if(server.argName(i).startsWith("program_btn"))
      program_control = server.arg(i).toInt();
    if(server.argName(i).startsWith("speed"))
      program_speed = server.arg(i).toInt();
    if(server.argName(i).startsWith("density"))
      program_density = server.arg(i).toInt();
    if(server.argName(i).startsWith("brightness"))
      program_brightness = server.arg(i).toInt();
  }
  if(program_control == 0)
    output_state();
  create_message();
  webString = message;
  #if 0
  // some debugging print post/get messages
  webString += ( server.method() == HTTP_GET ) ? "GET" : "POST";
  for (int i = 0; i < server.args(); i++ )
  {
    webString += " " + server.argName(i) + ": " + server.arg(i);
  };
  #endif
  server.send(200, "text/html", webString);
  countdown = COUNTDOWN_CYCLES;
}

// fancy css color button example
void handle_cssButton()
{
  const char * cssButton ="<!DOCTYPE html>"
"<html>"
"<head>"
"<style>"
".button {"
"background-color: #990033;"
"border: none;"
"color: white;"
"padding: 7px 15px;"
"text-align: center;"
"cursor: pointer;"
"}"
"</style>"
"</head>"
"<body>"
"<input type=\"button\" class=\"button\" value=\"Input Button\">"
"</body>"
"</html>";

  server.send(200, "text/html", cssButton);
}
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
void loop() {
  static int connect_requested = 1;
  #if USE_OTA
  // Handle OTA server.
  ArduinoOTA.handle();
  #endif
  // Handle web server
  server.handleClient();
  if(countdown > 0)
    countdown--;
  else
  {
    if(program_control > 0)
      program();
    if(allow_interrupts == 0)
      noInterrupts();
    strip.show(); // it will disable interrupts
    interrupts(); // re-enable interrupts
    if(WiFi.status() == WL_CONNECTED)
    {
      digitalWrite(LED_BUILTIN, LOW); // LED ON
      connect_requested = 0; // if we loose connection, we have to reboot
    }
    else
    {
      digitalWrite(LED_BUILTIN, HIGH); // LED OFF
      // we were connected -> reboot to reconnect
      if(connect_requested == 0 && ap_mode == 0)
      {
        proper_reboot_pins();
        // explicitely reset
        // warning - reset won't work after sketch is uploaded.
        // but after power off/on it should work
        ESP.reset();
        // or reset in 6 seconds by hard watchdog
        // some problem in watchdog reset...
        ESP.wdtDisable();
        while(1){} // wait for watchdog to reset
      }
    }

  }
  ESP.wdtFeed();
#if 0
  // Some example procedures showing how to display to the pixels:
  colorWipe(strip.Color(255,   0,   0), 40); // Red
  colorWipe(strip.Color(255, 127,   0), 40); // Orange
  colorWipe(strip.Color(  0, 255,   0), 40); // Green
  colorWipe(strip.Color(  0, 127, 127), 40); // Cyan
  colorWipe(strip.Color(  0,   0, 255), 40); // Blue
  colorWipe(strip.Color(255,   0, 127), 40); // Violett
  colorWipe(strip.Color(  0,   0,   0), 40); // Black
  //colorWipe(strip.Color(0, 0, 0, 255), 40); // White RGBW
  //delay(1000);
  for(int i = 0; i < 3; i++)
    rainbow(20);
  // Send a theater pixel chase in...
  theaterChase(strip.Color(255, 127,   0), 16, 2, 20); // Orange
  theaterChase(strip.Color(255,   0, 127), 16, 2, 20); // Violett
  theaterChase(strip.Color(127, 127, 127), 16, 2, 20); // White
  rainbowCycle(20);
  theaterChaseRainbow(32, 20);
#endif
}

// Fill the dots one after the other with a color
void colorWipe(uint32_t c, uint8_t wait) {
  for(uint16_t i=0; i<strip.numPixels(); i++) {
    strip.setPixelColor(i, c);
    strip.show();
    delay(wait);
  }
}

void rainbow(uint8_t wait) {
  uint16_t i, j;

  for(j=0; j<256; j++) {
    for(i=0; i<strip.numPixels(); i++) {
      strip.setPixelColor(i, Wheel((i+j) & 255));
    }
    strip.show();
    delay(wait);
  }
}

// Slightly different, this makes the rainbow equally distributed throughout
void rainbowCycle(uint8_t wait) {
  uint16_t i, j;

  for(j=0; j<256*5; j++) { // 5 cycles of all colors on wheel
    for(i=0; i< strip.numPixels(); i++) {
      strip.setPixelColor(i, Wheel(((i * 256 / strip.numPixels()) + j) & 255));
    }
    strip.show();
    delay(wait);
  }
}

//Theatre-style crawling lights.
void theaterChase(uint32_t c, uint8_t every, uint8_t n, uint8_t wait) {
  for (int j=0; j<n; j++) {  //do n cycles of chasing
    for (int q=0; q < every; q++) {
      for (uint16_t i=0; i < strip.numPixels(); i=i+every) {
        strip.setPixelColor(i+q, c);    //turn every nth pixel on
      }
      strip.show();

      delay(wait);

      for (uint16_t i=0; i < strip.numPixels(); i=i+every) {
        strip.setPixelColor(i+q, 0);        //turn every nth pixel off
      }
    }
  }
}

//Theatre-style crawling lights with rainbow effect
void theaterChaseRainbow(uint8_t every, uint8_t wait) {
  for (int j=0; j < 256; j+=16) {     // cycle all 256 colors in the wheel
    for (int q=0; q < every; q++) {
      for (uint16_t i=0; i < strip.numPixels(); i=i+every) {
        strip.setPixelColor(i+q, Wheel( (i+j) % 255));    //turn every third pixel on
      }
      strip.show();

      delay(wait);

      for (uint16_t i=0; i < strip.numPixels(); i=i+every) {
        strip.setPixelColor(i+q, 0);        //turn every third pixel off
      }
    }
  }
}

// Input a value 0 to 255 to get a color value.
// The colours are a transition r - g - b - back to r.
uint32_t Wheel(byte WheelPos) {
  WheelPos = 255 - WheelPos;
  if(WheelPos < 85) {
    return strip.Color(255 - WheelPos * 3, 0, WheelPos * 3);
  }
  if(WheelPos < 170) {
    WheelPos -= 85;
    return strip.Color(0, WheelPos * 3, 255 - WheelPos * 3);
  }
  WheelPos -= 170;
  return strip.Color(WheelPos * 3, 255 - WheelPos * 3, 0);
}

uint32_t Wheel_bright(byte WheelPos, byte brightness) {
  uint32_t r,g,b;
  WheelPos = 255 - WheelPos;
  if(WheelPos < 85) {
    r = 255 - WheelPos * 3;
    g = 0;
    b = WheelPos * 3;
  } else
  if(WheelPos < 170) {
    WheelPos -= 85;
    r = 0;
    g = WheelPos * 3;
    b = 255 - WheelPos * 3;
  } else
  {
    WheelPos -= 170;
    r = WheelPos * 3;
    g = 255 - WheelPos * 3;
    b = 0;
  }
  r = r * brightness / 256;
  g = g * brightness / 256;
  b = b * brightness / 256;
  return strip.Color(r, g, b);
}

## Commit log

2016-05-28 add thread library
    [polyScrewThread.scad]
2016-05-28 replacing obsolete triangles with new faces
    [polyScrewThread.scad]
2016-06-04 increasing inner diameter of the reflector thread to 12.4 mm to fit tolaerance of the screw printed as 12.0 mm
    [dodecastar.scad]
2017-05-28 2 half-star with 2 screws
    [dodecastar.scad]
2017-06-01 update half with screw mount
    [dodecastar.scad]
2017-06-01 parametric screw hole
    [dodecastar.scad]
2017-06-02 add parametric screw hole and cable holder space
    [dodecastar.scad]
2017-06-02 icreasing screw hole
    [dodecastar.scad]
2017-06-02 parametrizing and adjusting screw head hole dimensions
    [dodecastar.scad]
2017-06-03 orienting half-star flat on xy plane
    [dodecastar.scad]
2017-06-04 screw parameters as function arguments
    [dodecastar.scad]
2017-06-04 trying to fix when screw length is small and gets deep into the material
    [dodecastar.scad]
2017-06-04 fixing screw hole deep inside issue
    [dodecastar.scad]
2017-06-04 fixing main screw issues, printing
    [dodecastar.scad]
2017-06-04 fixing screw holes, but now object is not manifold
    [dodecastar.scad]
2017-06-04 fixing manifold
    [dodecastar.scad]
2017-06-04 nut_d passed as argument
    [dodecastar.scad]
2017-06-04 fixing screw leader nut too thin near the head
    [dodecastar.scad]
2017-06-04 increase screw head holder thicknes to fix void hear head when sliced
    [dodecastar.scad]
2017-06-04 additionally fix screw head nut
    [dodecastar.scad]
2017-06-04 fixing manifold issue
    [dodecastar.scad]
2017-06-08 rendering with blender
    [dodecastar.blend]
2017-06-24 fix syntax error falsee->false
    [dodecastar.scad]
2017-06-24 increase screw "nut" hole dia 1.5->1.7 mm
    [dodecastar.scad]
2017-06-24 screw length too deep (protrudes thru other side)
    [dodecastar.scad]
2017-07-23 readme with LED string picture
2017-07-23 shorten screw length
    [dodecastar.scad]
2017-07-23 Add slightly modified arduino "strandtest" source
2017-07-23 circuit box
    [upbox.scad]
2017-07-24 Web server LED control. Not very stable...
2017-07-24 blink onboard LED
2017-07-24 Found out web interface instability: More than 10 leds: interrupts are disabled for too long. Workaround is to remove "noInterrupts()" call from Adafruit NeoPixel library, but LEDs will flicker then.
2017-07-24 interrupts on/off from web interface
2017-07-24 some web stability update and fancy css button example
2017-07-25 random LEDs program
2017-07-25 Change ledstrip pin 2->14 Pins 0.2,15 need to be free for proper reboot
    [strandtest.ino]
2017-12-28 3 different sizes and bugfix to clear screw depth hole
    [dodecastar.scad]
2018-12-25 holder for the star of 2x normal size
    [dodecastar.scad]
2018-12-25 arduino blinkenlights applications
